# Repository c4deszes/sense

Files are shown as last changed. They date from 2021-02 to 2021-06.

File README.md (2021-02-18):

# Environment sensor



> This project implements an environment sensor, including PCB, enclosure and
software.

---

## Features

+ WiFi connection, configuration in AP mode
+ Publishes messages over MQTT
+ Measures several values, including:
  + Temperature
  + Humidity
  + Pressure
  + Dust concentration
  + Wind speed
  + Light level

## Help

### Documentation

The project uses AsciiDoctor as it's primary documentation format and Markdown
in a few places, such as this README.

[AsciiDoctor reference](https://docs.asciidoctor.org/asciidoc/latest/)

[AsciiDoctor Gradle plugin](https://asciidoctor.github.io/asciidoctor-gradle-plugin/development-3.x/user-guide)

### Traceability

Project is setup to have traceability from requirements to implementation and
verification but hasn't decided on a tool yet.

## License



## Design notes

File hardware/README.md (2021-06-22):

# Sensor Hardware

## Requirements

[List of hardware requirements](./docs/requirements)

## Design

[Hardware design overview](./docs/design/hardware.adoc)

## Development process

Development process according to [Hardware SPICE](https://www.intacs.info/images/uploads/intacs_HW_Engineering_PRM_PAM_v20.pdf).

---

## Development tools

| Tool | Version | Purpose |
|--|--|--|
| KiCAD | 5.1+ | Schematic design, PCB layout |
| Python | 3.8+ | *Optional*, used for scripted workflow |

---

## Continuous Integration

GitHub Actions is used for automatically testing some aspects of the design on
each change.

[KiBot](https://github.com/INTI-CMNB/kibot)

[KiCAD Export actions](https://github.com/nerdyscout/kicad-exports)

---

## Helpful links

[Hardware Software Interface](https://nqa2.iscn.com/images/PdfFiles/experience-aspice-safety-integrated.pdf)

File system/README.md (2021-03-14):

# Sensor System

## Requirements

[List of system requirements](./docs/requirements)

## Architecture

[System architecture overview](./docs/architecture/system.adoc)

---

## Continuous Integration

GitHub Actions is used for the system tests that can automatically executed.

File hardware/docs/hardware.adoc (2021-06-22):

= Hardware domain overview

== Hardware Requirements

- xref:requirements/power.adoc[Power requirements]
- xref:requirements/sensor.adoc[Sensor requirements]

== Hardware Design

- xref:design/hardware.adoc[Hardware design overview]
- xref:design/controller.adoc[Controller design]
- xref:design/power.adoc[Power design]
- xref:design/sensor.adoc[Sensor design]
- xref:design/windsensor.adoc[Wind Sensor design]

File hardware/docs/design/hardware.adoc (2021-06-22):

= Hardware design

== Design overview

[plantuml,software-architecture-details,svg]
....
@startuml
!include C4_Component.puml

LAYOUT_LEFT_RIGHT()

title Sensor Hardware

System_Boundary(hardware, "Hardware") {
	Component(power, "Power", "Power", "Provides power to all components")

	System_Boundary(sensor, "Sensor") {
		Component(bme280, "BME280", "Sensor")
		Component(bh1750, "BH1750", "Sensor")
		Component(gp2y1010au, "GP2Y1010AU", "Sensor")
	}

	Component(windsensor, "Wind Sensor", "Sensor", "")

	Component(controller, "Controller", "", "")

	Rel(power_connector, power, "Power")
}
....

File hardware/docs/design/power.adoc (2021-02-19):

= Power design

== DC/DC converter

link:https://www.st.com/resource/en/datasheet/l5973d.pdf[L5973D Datasheet]

link:https://www.st.com/resource/en/application_note/cd00043744-designing-with-the-25-a-dcdc-converter-l5973d-stmicroelectronics.pdf[L5973D Application note]

== Linear regulator

link:https://www.microchip.com/wwwproducts/en/MIC5234[MIC5234 Datasheet]

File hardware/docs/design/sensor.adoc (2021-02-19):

= Sensor design

== Temperature/Humidity/Pressure Sensor

link:https://www.bosch-sensortec.com/media/boschsensortec/downloads/datasheets/bst-bme280-ds002.pdf[BME280 Datasheet]

== Light Sensor

link:https://www.mouser.com/datasheet/2/348/bh1750fvi-e-186247.pdf[BH1750 Datasheet]

== Dust Sensor

link:https://global.sharp/products/device/lineup/data/pdf/datasheet/gp2y1010au_e.pdf[GP2Y1010AU Datasheet]

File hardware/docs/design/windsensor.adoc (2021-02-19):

= Wind Sensor design

== Constant Power supply

link:https://datasheets.maximintegrated.com/en/ds/MAX4210-MAX4211.pdf[MAX4210 Datasheet]

link:https://www.maximintegrated.com/en/design/technical-documents/app-notes/4/4470.html[MAX4210 Constant Power PSU Application note]

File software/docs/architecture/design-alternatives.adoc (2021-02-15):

= Software architecture Design alternatives

== No aggregate

The Sensor Aggregator may be seen as a monolith pattern, the alternative would
be to wire each sensor to the modules that depend on it.

|===
|*Pro* | *Con*

|Monolith is avoided, in case of a new sensor only the dependent modules have to
be modified
|Too many dependencies having to be injected into the other modules
|===

== Merging Application Main with Signal Publisher

The Signal Publisher doesn't have many responsibilities therefore it could
be merged into Application Main.

|===
|*Pro* | *Con*

|Reduces complexity of the architecture
|Increases complexity of Application Main
|===

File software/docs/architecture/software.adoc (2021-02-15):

= Software architecture overview

This document describes the overall software architecture and their interactions,
as well as integration of the software into larger systems.

== Architecture

Below is a diagram of the software architecture.

[plantuml,software-architecture-details,svg]
....
@startuml
!include C4_Component.puml

LAYOUT_LEFT_RIGHT()

title Sensor Software Architecture

System_Boundary(software, "Software") {
	System_Boundary(comm, "Communication Layer") {
		Component(wifi, "WiFi Connection Manager", "WiFi", "Provides access to the WiFi connection")
		Component(mqtt, "MQTT Connection Manager", "Mqtt", "Provides access to the MQTT connection")
		Component(serial, "Serial Connection Manager", "Serial", "Provides access to the Serial connection")

		Rel(mqtt, wifi, "GetNetworkInterface")
	}
	System_Boundary(sensor, "Sensor Layer") {
		Container(sensor_aggregator, "Sensor Aggregator", "Sensors", "Aggregates all sensor values and states into a single interface")
		Component(temperature, "Temperature Sensor", "Sensor", "Provides temperature values")
		Component(humidity, "Humidity Sensor", "Sensor", "Provides humidity values")
		Component(pressure, "Pressure Sensor", "Sensor", "Provides pressure values")
		Component(dust, "Dust Sensor", "Sensor", "Provides dust concentration values")
		Component(light, "Light Sensor", "Sensor", "Provides light level values")
		Component(wind, "Wind Sensor", "Sensor", "Provides wind speed values")

		Component(power, "Power Handler", "Sensor", "Provides power monitoring and low power control")

		Rel(sensor_aggregator, temperature, "GetValue")
		Rel(sensor_aggregator, humidity, "GetValue")
		Rel(sensor_aggregator, pressure, "GetValue")
		Rel(sensor_aggregator, dust, "GetValue")
		Rel(sensor_aggregator, light, "GetValue")
		Rel(sensor_aggregator, wind, "GetValue")
		Rel(sensor_aggregator, power, "GetValue")
		Rel(sensor_aggregator, power, "Enter Low Power Mode")
	}
	System_Boundary(app, "Application Layer") {
		Component(application, "Application Main", "Application", "Executes main application code")
		Component(configuration, "Configuration Manager", "Configuration", "Provides access to non-volatile memory")
		Component(diagnostics, "Diagnostics Controller", "Diagnostics", "Provides diagnostic access to the device")
		Component(publisher, "Signal Publisher", "Publisher", "Periodically sends out sensor values")

		Rel(application, publisher, "")
		Rel(application, diagnostics, "")
		Rel(application, configuration, "")
	}

	Rel(diagnostics, wifi, "GetNetworkInterface")
	Rel(diagnostics, serial, "GetSerialInterface")
	Rel(diagnostics, sensor_aggregator, "GetSensorValues")
	Rel(publisher, mqtt, "Publish Message")
	Rel(publisher, sensor_aggregator, "GetSensorValues")
	Rel(application, sensor_aggregator, "Enter Low Power Mode")
}

System_Ext(hardware, "Hardware") {
	Component_Ext(powerstage, "DC/DC", "Power")
	Component_Ext(bme280, "BME280", "Ambient sensor")
	Component_Ext(gp2y1010au, "GP2Y1010", "Dust sensor")
	Component_Ext(bh1750, "BH1750", "Light sensor")
	Component_Ext(anemometer, "Anemometer", "Wind sensor")
	Component_Ext(ublox, "U-Blox NINA", "WiFi")
	Component_Ext(uart, "UART Header", "")
	Component_Ext(nvram, "AT24C02", "NVRAM")
}

BiRel(power, powerstage, "Control/Monitor", "Analog/Digital")
BiRel(temperature, bme280, "Communication", "I2C")
BiRel(humidity, bme280, "Communication", "I2C")
BiRel(pressure, bme280, "Communication", "I2C")
BiRel(dust, gp2y1010au, "Control", "Analog")
BiRel(light, bh1750, "Communication", "I2C")
BiRel(wind, anemometer, "Control", "Analog")
BiRel(wifi, ublox, "Communication", "SPI")
BiRel(serial, uart, "Communication", "UART")
BiRel(configuration, nvram, "Communication", "I2C")

@enduml
....

=== Elements

==== Application Layer

- xref:elements/application/ApplicationMain.adoc[Application Main]
- xref:elements/application/ConfigurationManager.adoc[Configuration Manager]
- xref:elements/application/DiagnosticsController.adoc[Diagnostics Controller]
- xref:elements/application/SignalPublisher.adoc[Signal Publisher]

==== Communication Layer

- xref:elements/communication/MQTTConnectionManager.adoc[MQTT Connection Manager]
- xref:elements/communication/SerialConnectionManager.adoc[Serial Connection Manager]
- xref:elements/communication/WiFiConnectionManager.adoc[WiFi Connection Manager]

==== Sensor Layer

- xref:elements/sensor/DustSensor.adoc[Dust Sensor]
- xref:elements/sensor/HumiditySensor.adoc[Humidity Sensor]
- xref:elements/sensor/LightSensor.adoc[Light Sensor]
- xref:elements/sensor/PowerHandler.adoc[Power Handler]
- xref:elements/sensor/PressureSensor.adoc[Pressure Sensor]
- xref:elements/sensor/TemperatureSensor.adoc[Temperature Sensor]
- xref:elements/sensor/WindSensor.adoc[Wind Sensor]

== Software integration

=== Standard mode (MQTT)

When WiFi and MQTT settings are correctly configured then the sensors can publish
data through the MQTT broker and applications can subscribe to the messages.

[blockdiag,mqtt-integration,svg]
....
blockdiag {
  app [label = "Application"];
  broker [label = "MQTT Broker"];
  sensor1 [label = "Sensor 1"];
  sensor2 [label = "Sensor 2"];
  sensor3 [label = "Sensor 3"];

  app <- broker;
  broker <- sensor1;
  broker <- sensor2;
  broker <- sensor3;
}
....

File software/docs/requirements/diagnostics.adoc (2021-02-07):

= Diagnostics

This document specifies the diagnostic software requirements of the product.

== Requirements

=== Interfaces

The diagnostic mode shall be accessible via UART, the baudrate shall be 115200bps
with 8 data bit, even parity and a single stop bit (115200/8/E/1).

The diagnostic mode shall also be available in WiFi access point mode, and in
WiFi station mode if it's enabled.

=== Product information

In diagnostic mode the following commands shall be available:

- Read Serial Number
- Read MAC Address

=== Product state

In diagnostic mode the following commands shall be available:

- Read Power sensor
- Read Temperature sensor
- Read Humidity sensor
- Read Pressure sensor
- Read Dust sensor
- Read Wind speed sensor
- Read Light level sensor

- Reload configuration
- Reset

=== Connection state

In diagnostic mode the following commands shall be available:

- Read WiFi status
- Read Last WiFi station connection status
- Read MQTT connection status

- Reconnect

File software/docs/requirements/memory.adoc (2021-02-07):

= Memory and configuration

== Requirements

=== Product information

The software shall store information about the product instance.

The following product information shall be stored in non volatile memory.

- Product Serial number
- Software version number

=== WiFi configuration

The software shall store the WiFi configuration in non volatile memory.

The following WiFi settings shall be stored in non volatile memory.

- WiFi SSID
- WiFi Password

=== MQTT configuration

The software shall store the MQTT configuration in non volatile memory.

The following MQTT settings shall be stored in non volatile memory.

- MQTT broker hostname
- MQTT broker port
- MQTT username
- MQTT password
- MQTT topic name

=== Diagnostic settings

The software shall store the configuration of Diagnostics in non volatile memory.

The following diagnostic settings shall be stored in non volatile memory.

- Diagnostics over WiFi AP enabled
- Diagnostics over WiFi STA enabled

=== Dust sensor calibration information

The software shall store dust sensor calibration information in non volatile memory.

=== Anemometer calibration information

The software shall store wind sensor calibration information in non volatile memory.

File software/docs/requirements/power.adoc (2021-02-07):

= Power requirements

This document specifies the software requirements for managing product power.

== Requirements

=== Voltage monitoring

The product shall monitor it's input voltage and keep a 

=== Current consumption

The product shall not consume more than _maximum current_ under any operating conditions.

The produt shall not consume more than _sleep mode current_ in sleep mode.

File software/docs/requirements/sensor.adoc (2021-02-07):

= Sensor requirements

== Sensor stack

The following values are measured:

- Ambient temperature
- Relative humidity
- Air pressure
- Dust concentration
- Wind speed
- Light level

=== Capabilities

The product shall be able to measure environment states according to table below.

== Sensor states

On power on reset each sensor shall start in *NO_INIT* state.

The microcontroller shall attempt to initialize each sensor individually then
based on the internal communication, peripheral states shall decide whether
the sensor is functional and assign either *INIT_OK* or *INIT_ERROR* states
accordingly.

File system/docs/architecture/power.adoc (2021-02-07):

= Power component design

== Interface

The power interface provides physical power to hardware components, the input
voltage value and the input voltage state.

== Parameters

[format="csv", options="header"]
|===
include::system/params/power.csv[]
|===

== Power monitoring

=== States

The power component inherits the xref:sensor.adoc#States[sensor statemachine] and extends it with it's
own statemachine with the purpose of providing other components information of possibly damaging
or edge case conditions. Components may reference the states below and use them for error reactions.

[nomnoml]
....
#direction: right
#spacing: 60
[<start>s]->[<state>NA]
[<state>NA]->[<state>OK]
[<state>NA]overvoltage->[<state>HIGH]
[<state>NA]undervoltage->[<state>LOW]
[<state>OK]overvoltage->[<state>HIGH]
[<state>OK]undervoltage->[<state>LOW]
[<state>LOW]overvoltage->[<state>HIGH]
[<state>LOW]->[<state>OK]
[<state>HIGH]undervoltage->[<state>LOW]
[<state>HIGH]->[<state>OK]
....

==== Description

The component starts in an _NA_ state and switches between LOW, OK, HIGH states
after every sample depending on the sensed voltage value.

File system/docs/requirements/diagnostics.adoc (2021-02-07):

= Diagnostic requirements

This document specifies the diagnostic requirements of the product.

== Parameters

[format="csv", options="header"]
|===
include::system/params/communication.csv[]
|===

[format="csv", options="header"]
|===
include::system/params/diagnostics.csv[]
|===

== Requirements

=== Interfaces

The diagnostic mode shall be be accessible via UART headers on the PCB or via
a TCP server hosted when the product is in WiFi access point mode.

=== Product information

In diagnostic mode the following product information shall be readable:

- Product Serial number
- Product MAC address

=== Product state

In diagnostic mode the following status information shall be readable:

- Power state
- Temperature sensor state
- Humidity sensor state
- Pressure sensor state
- Dust sensor state
- Wind speed sensor state
- Light level sensor state

=== Connection state

In diagnostic mode the following connection status information shall be readable:

- Current WiFi connection mode
- Current WiFi connection status
- Last WiFi station connection status
- Current MQTT connection status

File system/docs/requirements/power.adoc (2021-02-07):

= Power requirements

This document specifies the requirements of the power input.

== Parameters

[format="csv", options="header"]
|===
include::system/params/power.csv[]
|===

== Requirements

=== Operational voltage

The product shall be operational when the supply voltage is above
<<Parameters,param_power_low_error>> and below
<<Parameters,param_power_high_error>>

=== Reverse voltage

The product shall be operational when the supply voltage is restored after
a reverse or negative supply voltage event.

=== Voltage monitoring

The product shall monitor it's input voltage.

=== Current consumption

The product shall not consume more than <<Parameters,param_power_max_current>>
under any operating conditions.

The produt shall not consume more than
<<Parameters,param_power_max_sleep_current>> in sleep mode.

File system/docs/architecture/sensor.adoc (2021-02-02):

= Sensor components

== Common sensor component

=== Interface

Each sensor provides the following values:

- Sensor state _(INIT_OK, INIT_ERROR)_
- Sensor value state _(OK, LOW, HIGH, etc.)_
- Sensor value (floating point)

=== States

Each sensor implements the following state machine:

[nomnoml]
....
[<start>st]->[<state>NO_INIT]
[<state>NO_INIT]->[<choice>Has Error?]
[<choice>Has Error?] no ->[<state>INIT_OK]
[<choice>Has Error?] yes -> [<state>INIT_ERROR]
....

== Temperature sensor

=== States

The temperature sensor implements a statemachine that can indicate
overtemperature and freeze conditions.

[nomnoml]
....
[<start>st]->[<state>NA]
[<state>NA]->[<state>OK]
[<state>NA]->[<state>LOW]
[<state>NA]->[<state>HIGH]
[<state>OK]->[<state>LOW]
[<state>LOW]->[<state>OK]
[<state>OK]->[<state>HIGH]
[<state>HIGH]->[<state>OK]
....

== Humidty sensor

=== States

The humidty sensor implements a statemachine that can indicate too high
humidity for certain components to operate in.

[nomnoml]
....
[<start>st]->[<state>NA]
[<state>NA]->[<state>OK]
[<state>NA]->[<state>HIGH]
[<state>OK]->[<state>HIGH]
[<state>HIGH]->[<state>OK]
....

== Air pressure sensor

=== States

The air pressure sensor implements a statemachine that goes into _OK_ state
after the first successful value acquisition. No error reaction is tied to it's
value in the current design.

[nomnoml]
....
[<start>st]->[<state>NA]
[<state>NA]->[<state>OK]
[<state>OK]
....

== Dust concentration sensor

=== States

The dust concentration sensor implements a statemachine that goes into _OK_ state
after the first successful value acquisition. No error reaction is tied to it's
value in the current design.

[nomnoml]
....
[<start>st]->[<state>NA]
[<state>NA]->[<state>OK]
[<state>OK]
....

== Wind speed sensor

=== States

The wind speed sensor (anemometer) implements a statemachine that goes into _OK_ state
after the first successful value acquisition. Furthermore the anemometer may be be
disabled for hardware protection as well as go into a _SATURATED_ state where
the sensor value may start to max out.

[nomnoml]
....
[<start>st]->[<state>NA]
[<state>NA]->[<state>OK]
[<state>OK]->[<state>DISABLED]
[<state>DISABLED]->[<state>OK]
[<state>OK]->[<state>SATURATED]
[<state>SATURATED]->[<state>OK]
[<state>SATURATED]->[<state>DISABLED]
....

== Light level sensor

=== States

The light level sensor implements a statemachine that goes into _OK_ state
after the first successful value acquisition. No error reaction is tied to it's
value in the current design.

[nomnoml]
....
[<start>st]->[<state>NA]
[<state>NA]->[<state>OK]
[<state>OK]
....

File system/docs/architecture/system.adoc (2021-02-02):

= System architecture

This document describes the overall system architecture, along with examples of
how this product is integrated into larger systems.

== Architecture

The following diagram describes the product's internal architecture

[blockdiag]
....
blockdiag {
	power_in [label = "Power In"];
	power [label = "DC/DC converter"];
	communication [label = "u-blox NINA-W102"];
	processor [label = "ATSAMD21G18A"];
	boschsensor [label = "BME280"];
	dustsensor [label = "GP2Y1010AU"];
	lightsensor [label = "BH1750"];
	anemometer [label = "Anemometer"];

	power_in -> power;
	power -> processor;
	communication <-> processor;
	processor <- boschsensor;
	processor <- dustsensor;
	processor <- lightsensor;
	processor <-> anemometer;
}
....

=== Detailed designs

- xref:power.adoc[Power component]
- xref:sensor.adoc[Sensor]
- xref:communication.adoc[Communication]

== Product integration

The product is intended to be integrated into a larger system consisting of
multiple sensors and potentially actuators.

The product can be part of a network where multiple sensors publish messages
to the same message broker.

[nwdiag]
....
nwdiag {
  network WiFi {
    "MQTT broker" [address = "mqtt.broker.local"];
    Sensor1 [address = "192.168.1.2"];
    Sensor2 [address = "192.168.1.3"];
	Sensor3 [address = "192.168.1.4"];
  }
}
....

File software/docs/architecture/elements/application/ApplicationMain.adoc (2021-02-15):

= Application Main

The application main handles the software initialization after reset, the cyclic update of components and the main state transitions such as low power mode.

== Requirements

== Interfaces

=== Setup

[cols="h,1"]
|===
|Function |setup
|Returns |-
|Description |Initializes all the other software components
|===

=== Loop

[cols="h,1"]
|===
|Function |loop
|Returns |-
|Description |Periodically updates all the software components
|===

== Dynamic behavior

[nomnoml]
....
[<start>st] power on reset -> [<state>setup]
[<state>setup] initialized -> [<state>loop]
[<state>loop] -> [<state>loop]
....

== Resource consumption

=== Memory

[cols="h,1"]
|===
|RAM |5%
|ROM |5%
|===

=== Runtime

|===
|Function |Average |Max
|setup |100ms |500ms
|loop |100ms |500ms
|===

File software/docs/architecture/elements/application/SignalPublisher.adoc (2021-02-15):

= Application Main

== Requirements

== Interfaces

=== Publish

[cols="h,1"]
|===
|Function |publish
|Returns |-
|Description |Publishes the current sensor values over MQTT
|===

== Dynamic behavior

// TODO: describe dynamic behavior

== Resource consumption

=== Memory

[cols="h,1"]
|===
|RAM |<1%
|ROM |1%
|===

=== Runtime

|===
|Function |Average |Max
|publish |10ms |100ms
|===

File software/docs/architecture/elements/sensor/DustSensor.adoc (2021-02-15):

= Dust Sensor

== Requirements

== Interfaces

=== Initialize

[cols="h,1"]
|===
|Function |begin
|Returns |-
|Description |Initializes the sensor hardware
|===

=== GetState

[cols="h,1"]
|===
|Function |getState
|Returns |Sensor state `INIT_OK` or `INIT_ERROR`
|Description |Returns sensor hardware state
|===

=== GetValue

[cols="h,1"]
|===
|Function |getValue
|Returns |Sensor value `float`
|Description |Returns currently measured sensor value
|===

=== GetValueState

[cols="h,1"]
|===
|Function |getValueState
|Returns |Sensor value
|Description |Returns sensor value state
|===

== Dynamic behavior

//TODO: describe dynamic behavior

== Resource consumption

=== Memory

[cols="h,1"]
|===
|RAM |<1%
|ROM |1%
|===

=== Runtime

|===
|Function |Average |Max
|begin |50ms |100ms
|getValue |10ms |20ms
|===

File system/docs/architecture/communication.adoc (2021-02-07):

= Communication component

== Interface

The communication component provides the following interfaces:

- WiFi connection
- MQTT connection
- Diagnostic input and output

== Parameters

[format="csv", options="header"]
|===
include::system/params/communication.csv[]
|===

== States

=== WiFi

The following diagram describes the WiFi connection's statemachine.

[nomnoml]
....
[<start>st]->[<state>NO_INIT]
[<state>NO_INIT]->[<choice>Has module error?]
[Has module error?] no ->[<state>AP_MODE]
[Has module error?] yes -> [<state>INIT_ERROR]
[AP_MODE] on timer elapsed & wifi ssid configured & no client connected -> [<state>STA_DISCONNECTED]
[STA_DISCONNECTED] on first attempt / retry timeout -> [<state>STA_CONNECTING]
[STA_CONNECTING] on success -> [<state>STA_CONNECTED]
[STA_CONNECTING] on timeout -> [STA_DISCONNECTED]
[STA_CONNECTED] on dropout -> [STA_DISCONNECTED]
....

==== Description

The component starts in uninitialized state and goes into Access Point mode if
the module initialization has succeeded. The component stays in this state until
either a client is connected, the internal timer has not elapsed or WiFi settings
are not configured. Once all of this conditions are gone the component will attempt
to connect to the configured Access Point.

=== MQTT

The following diagram describes the MQTT connection's statemachine.

[nomnoml]
....
[<start>st]->[<state>NO_INIT]
[<state>NO_INIT] on WiFi entering STA_CONNECTED -> [<state>MQTT_DISCONNECTED]
[MQTT_DISCONNECTED] on first attempt / retry timeout -> [<state>MQTT_CONNECTING]
[<state>MQTT_CONNECTING] on success -> [<state>MQTT_CONNECTED]
[MQTT_CONNECTING] on timeout -> [MQTT_DISCONNECTED]
[MQTT_CONNECTED] on dropout -> [MQTT_DISCONNECTED]
....

==== Description

The component starts in uninitialized state and goes into disconnected state once
WiFi has successfully connected to an Access Point. The component then will try
and periodically attempt to connect to the configured broker.

Once the device has successfully connected it will start broadcasting the sensor
values.

=== Diagnostics

The following diagram describes the Diagnostic TCP server's statemachine.

[nomnoml]
....
[<start>st]->[<state>NO_INIT]
[<state>NO_INIT] on WiFi AP Mode -> [<state>DIAGNOSTIC_TCP_DISCONNECTED]
[<state>DIAGNOSTIC_TCP_DISCONNECTED] on connect -> [<state>DIAGNOSTIC_TCP_CONNECTED]
[<state>DIAGNOSTIC_TCP_DISCONNECTED] on timeout -> [<end>end]
[<state>DIAGNOSTIC_TCP_CONNECTED] on disconnect -> [<state>DIAGNOSTIC_TCP_DISCONNECTED]
[<state>DIAGNOSTIC_TCP_CONNECTED] on connection forced -> [<end>end]
....

==== Description

The component starts in uninitialized state and goes into disconnected state once
the WiFi has entered Access Point mode. The component will wait for a TCP connection
on the diagnostic TCP port, while this connection

== Sequences

=== First boot

Device is not yet configured, configuration is provided by the user via
diagnostic TCP server.

[seqdiag]
....
seqdiag {
  Communication -> WiFi [label = "InitModule"];
  Communication <-- WiFi [label = "INIT_OK"];

  Communication -> WiFi [label = "StartAp"];
  Communication <-- WiFi [label = "AP_MODE"];

  === User configures WiFi & MQTT settings ===

  Communication -> Diagnostics [label = "ConnectClient"];
  Communication <-- Diagnostics [label = ""];

  Diagnostics -> WiFi [label = "Set Configuration"];
  Diagnostics <-- WiFi [label = "OK"];

  Diagnostics -> MQTT [label = "Set Configuration"];
  Diagnostics <-- MQTT [label = "OK"];

  Diagnostics -> Communication [label = "Reload"];
  Diagnostics <-- Communication [label = ""];

  === Communication Startup ===

  Communication -> WiFi [label = "StartSta"];
  Communication <-- WiFi [label = "STA_CONNECTED"];

  Communication -> MQTT [label = "ConnectMqtt"];
  Communication <-- MQTT [label = "MQTT_CONNECTED"];
}
....

=== Successful connection

Device is already configured with the correct WiFi and MQTT settings and the
connections succeed.

[seqdiag]
....
seqdiag {
  Communication -> WiFi [label = "InitModule"];
  Communication <-- WiFi [label = "INIT_OK"];

  Communication -> WiFi [label = "StartAp"];
  Communication <-- WiFi [label = "AP_MODE"];

  ... AP Mode timeout, no active connection ...

  Communication -> WiFi [label = "StartSta"];
  Communication <-- WiFi [label = "STA_CONNECTED"];

  Communication -> MQTT [label = "ConnectMqtt"];
  Communication <-- MQTT [label = "MQTT_CONNECTED"];
}
....

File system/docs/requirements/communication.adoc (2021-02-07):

= Communication requirements

This document specifies the communication requirements of the product.

== Parameters

[format="csv", options="header"]
|===
include::system/params/communication.csv[]
|===

== Requirements

=== WiFi Communication

The product shall act as a WiFi station.

=== WiFi Configuration

The WiFi configuration shall be configurable via the
xref:diagnostics.adoc[diagnostic mode].

=== WiFi States

On power on reset the product shall detect if there's a problem initializing
the WiFi module and set it's internal state accordingly.

On power on reset the product shall act a WiFi Access Point for atleast
<<Parameters,param_wifi_ap_por_timeout>> or more if there's an active client
connection, afterwards the product shall attempt to connect to the configured 
WiFi Access Point as a Station. 
If the WiFi isn't configured correctly (empty SSID) the product shall stay in
AP mode until configuration is set and the device is either reset or connection
is forced via diagnostic commands.

If the product is unable to connect within
<<Parameters,param_wifi_sta_connection_timeout>> then the product shall attempt
reconnecting after <<Parameters,param_wifi_sta_retry_timeout>>.

=== MQTT Communication

The product shall publish MQTT messages.

=== MQTT Configuration

The MQTT configuration shall be configurable via the
xref:diagnostics.adoc[diagnostic mode].

=== MQTT States

After the product has successfully connected to the configured WiFi Access Point
it shall attempt to connect to the configured MQTT broker, unless there's configuration
missing.

If the product is unable to connect within
<<Parameters,param_mqtt_connection_timeout>> then the product shall attempt
reconnecting after <<Parameters,param_mqtt_retry_tmeout>>.

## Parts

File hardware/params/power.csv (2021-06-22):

Id | Parameter | Value | Unit
param_power_input_min | Maximum Input Voltage | 6.0 | V
param_power_input_max | Maximum Input Voltage | 32.0 | V
param_power_reverse_leakage | Maximum Input Voltage | 100 | uA

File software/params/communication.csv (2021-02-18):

Id | Parameter | Value | Unit
param_mqtt_publish_interval | MQTT publish interval | 5000 | ms

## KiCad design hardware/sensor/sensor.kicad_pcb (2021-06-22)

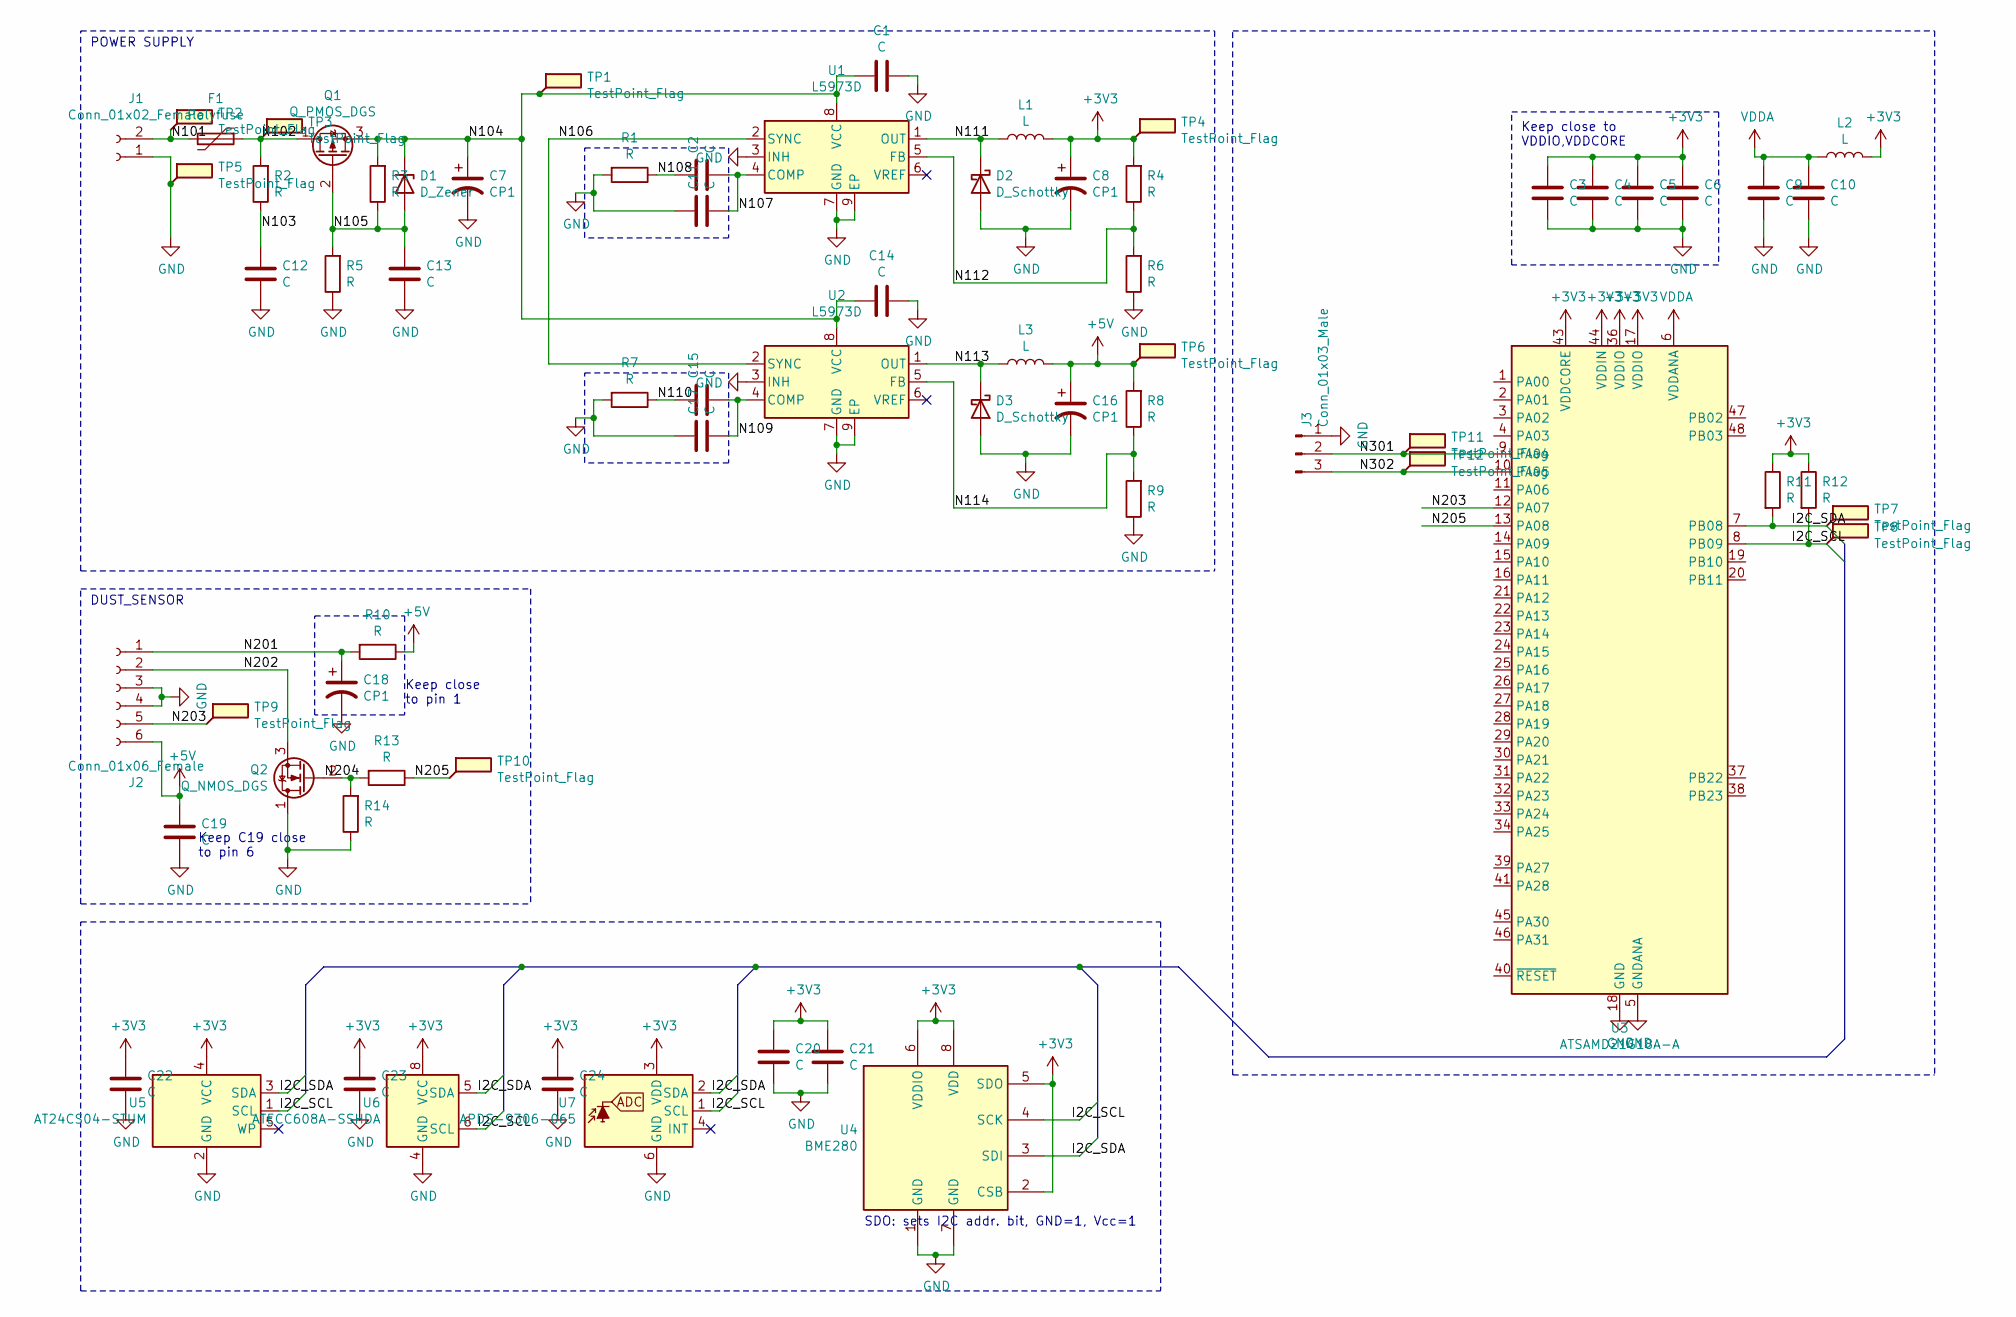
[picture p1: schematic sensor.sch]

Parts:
C1, C2, C3, C4, C5, C6, C9, C10, C11, C12, C13, C14, C15, C17, C19, C20, C21, C22, C23, C24: C; C_0603_1608Metric
C7, C8, C16, C18: CP1; CP_Elec_6.3x7.7
D1: D_Zener; D_SOD-110
D2, D3: D_Schottky; D_SMB_Handsoldering
F1: Polyfuse; Fuse_1812_4532Metric
J1: Conn_01x02_Female; JST_EH_S2B-EH_1x02_P2.50mm_Horizontal
J2: Conn_01x06_Female; PinHeader_1x06_P2.54mm_Vertical
J3: Conn_01x03_Male; PinHeader_1x03_P2.54mm_Vertical
L1, L3: L; L_Bourns-SRN4018
L2: L; L_0805_2012Metric
Q1: Q_PMOS_DGS; TO-252-2
Q2: Q_NMOS_DGS; SOT-23
R1, R2, R3, R4, R5, R6, R7, R8, R9, R10, R11, R12, R13, R14: R; R_0603_1608Metric
TP1, TP2, TP3, TP4, TP5, TP6, TP7, TP8, TP9, TP10, TP11, TP12: TestPoint_Flag; TestPoint_Pad_D1.5mm
U1, U2: L5973D; HSOP-8-1EP_3.9x4.9mm_P1.27mm_EP2.41x3.1mm_ThermalVias
U3: ATSAMD21G18A-A; TQFP-48_7x7mm_P0.5mm
U4: BME280; Bosch_LGA-8_2.5x2.5mm_P0.65mm_ClockwisePinNumbering
U5: AT24CS04-STUM; SOT-23-5
U6: ATECC608A-SSHDA; SOIC-8_3.9x4.9mm_P1.27mm
U7: APDS-9306-065; Broadcom_DFN-6_2x2mm_P0.65mm

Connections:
+3V3: C3.1, C4.1, C5.1, C6.1, C8.1, C20.1, C21.1, C22.1, C23.1, C24.1, L1.2, L2.2, R4.2, R11.1, R12.1, TP4.1, U3.17 (VDDIO), U3.36 (VDDIO), U3.43 (VDDCORE), U3.44 (VDDIN), U4.2 (CSB), U4.5 (SDO), U4.6 (VDDIO), U4.8 (VDD), U5.4 (VCC), U6.8 (VCC), U7.3 (VDD)
+5V: C16.1, C19.1, J2.6, L3.2, R8.2, R10.1, TP6.1
/I2C_SCL: R12.2, TP8.1, U3.8 (PB09), U4.4 (SCK), U5.1 (SCL), U6.6 (SCL), U7.1 (SCL)
/I2C_SDA: R11.2, TP7.1, U3.7 (PB08), U4.3 (SDI), U5.3 (SDA), U6.5 (SDA), U7.2 (SDA)
/N101: F1.2, J1.2, TP2.1
/N102: F1.1, Q1.1 (D), R2.2, TP3.1
/N103: C12.1, R2.1
/N104: C1.1, C7.1, C14.1, D1.1 (K), Q1.3 (S), R3.2, TP1.1, U1.8 (VCC), U2.8 (VCC)
/N105: C13.1, D1.2 (A), Q1.2 (G), R3.1, R5.2
/N106: U1.2 (SYNC), U2.2 (SYNC)
/N107: C2.2, C11.2, U1.4 (COMP)
/N108: C2.1, R1.1
/N109: C15.2, C17.2, U2.4 (COMP)
/N110: C15.1, R7.1
/N111: D2.1 (K), L1.1, U1.1 (OUT)
/N112: R4.1, R6.2, U1.5 (FB)
/N113: D3.1 (K), L3.1, U2.1 (OUT)
/N114: R8.1, R9.2, U2.5 (FB)
/N201: C18.1, J2.1, R10.2
/N202: J2.2, Q2.3 (S)
/N203: J2.5, TP9.1, U3.12 (PA07)
/N205: R13.1, TP10.1, U3.13 (PA08)
/N301: J3.2, TP11.1, U3.9 (PA04)
/N302: J3.3, TP12.1, U3.10 (PA05)
GND: C1.2, C3.2, C4.2, C5.2, C6.2, C7.2, C8.2, C9.2, C10.2, C11.1, C12.2, C13.2, C14.2, C16.2, C17.1, C18.2, C19.2, C20.2, C21.2, C22.2, C23.2, C24.2, D2.2 (A), D3.2 (A), J1.1, J2.3, J2.4, J3.1, Q2.1 (D), R1.2, R5.1, R6.1, R7.2, R9.1, R14.1, TP5.1, U1.3 (INH), U1.7 (GND), U1.9 (EP), U2.3 (INH), U2.7 (GND), U2.9 (EP), U3.5 (GNDANA), U3.18 (GND), U3.35 (GND), U3.42 (GND), U4.1 (GND), U4.7 (GND), U5.2 (GND), U6.4 (GND), U7.6 (GND)
unnamed: Q2.2 (G), R13.2, R14.2
VDDA: C9.1, C10.1, L2.1, U3.6 (VDDANA)

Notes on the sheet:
SDO: sets I2C addr. bit, GND=1, Vcc=1
DUST_SENSOR
POWER SUPPLY
Keep close to pin 1
Keep C19 close to pin 6
Keep close to VDDIO,VDDCORE

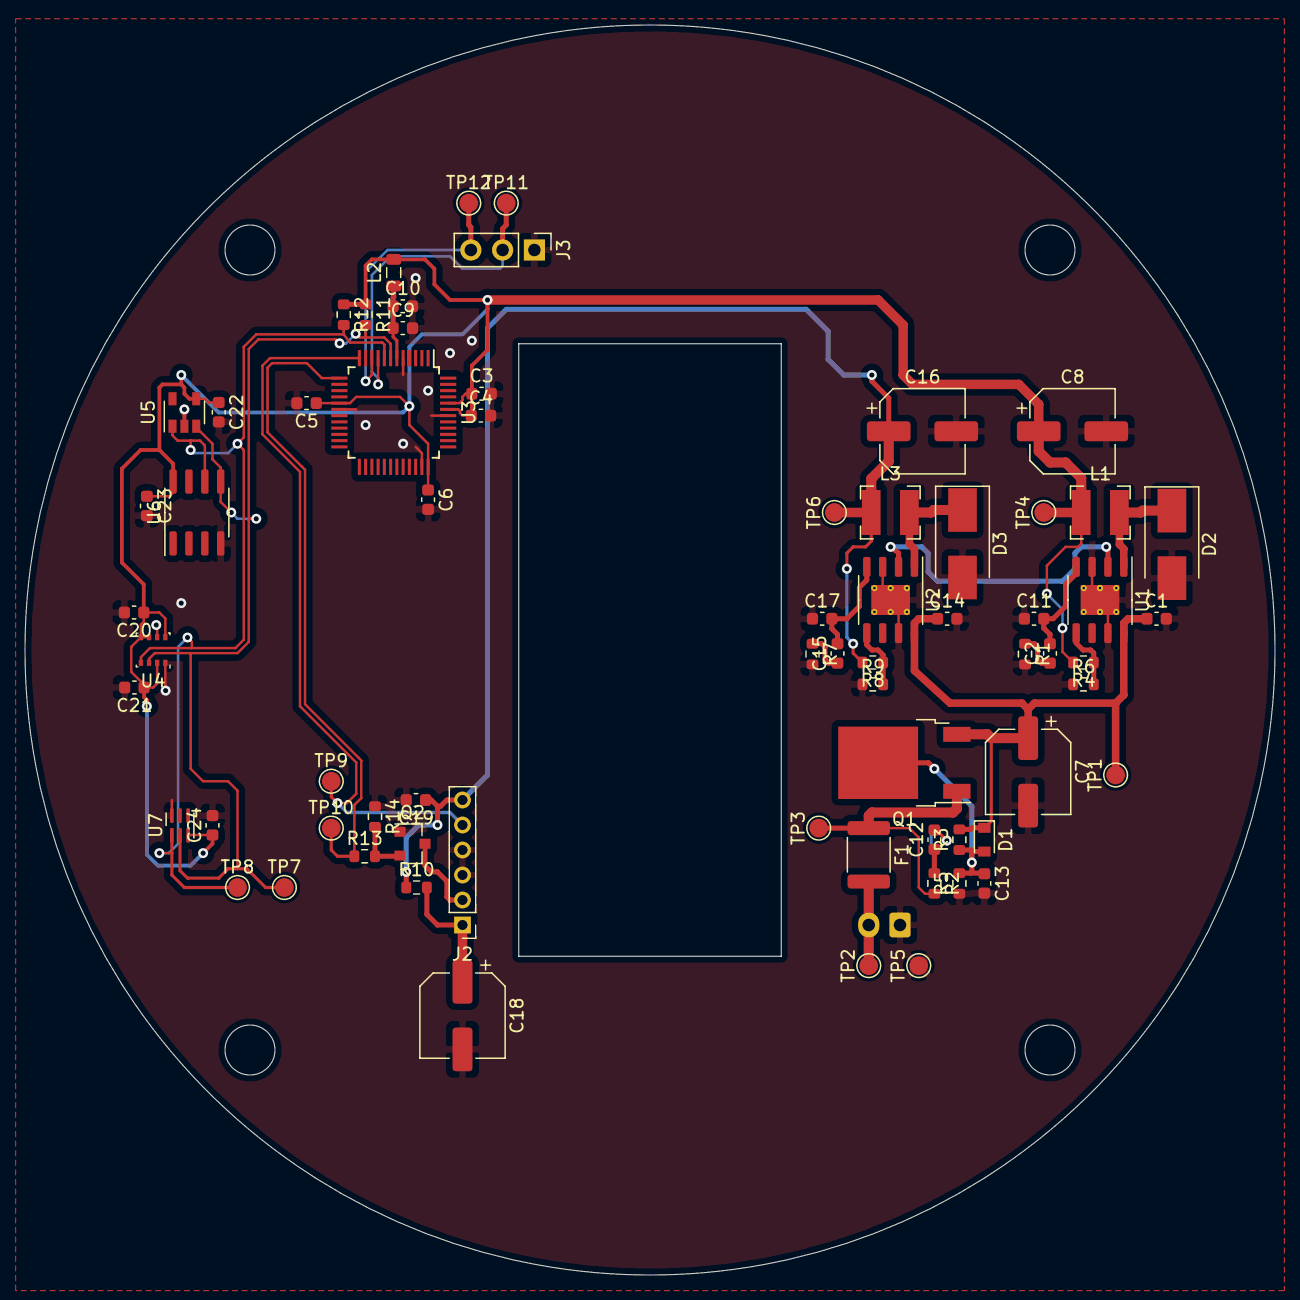
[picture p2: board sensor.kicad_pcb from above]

Board: 2 copper layers, 100.0 x 100.0 mm, 69 parts (1 on the bottom side), 27 nets.

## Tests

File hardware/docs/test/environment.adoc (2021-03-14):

= Test Environment

== Scope

- Power stage validation
- Anemometer driver circuit validation
- Temperature measurements
- Signal integrity check (I2C, UART signals)

== Instrumentation

=== Power supply

A programmable power supply is used to carry out measurements at different
input voltages.

=== Oscilloscope

An oscilloscope is used to check signal integrity.

=== DAQ

A Data acqusition unit is used to measure internal temperatures and validate
the internal signals of the anemometer circuit.

== Test framework

__TBD__

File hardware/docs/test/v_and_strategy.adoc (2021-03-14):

= Verification and Validation Strategy

== Process flow

[nomnoml]
....
[<start>st] -> [<choice>Design ready?]
[<choice>Design ready?]yes ->[<state>Perform electrical tests]
[<state>Perform electrical tests] success/failure -> [<end>release]
....

== Test Methods

=== Static testing

The hardware schematic and layout are tested within the toolchain for common
eletrical __(ERC)__ and design errors __(DRC)__.

== Test allocation

Static tests are automatically reexecuted on hardware design changes. The rest
may be partially automated or manual, depending on the complexity.

== Exit criteria

All tests must be executed before a hardware sample release and the release
report shall contain the measurements.

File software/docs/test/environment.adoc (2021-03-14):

= Test Environment

== Unit test environment

=== Scope

- Software component validation
- Application state transitions testing

== Hardware in loop environment

=== Scope

- Serial Diagnostic communication functional tests
- WiFi Diagnostic communication functional tests
- MQTT communication functional tests
- Memory configuration validation
- Voltage monitoring functional tests

=== Instrumentation

==== Power supply

A programmable power supply is used to test voltage monitoring feature.

==== Debugger

==== Serial device

A standard USB to Serial converter is used to communicate with the DUT over
the diagnostic channel.

=== Test framework

Pytest is used.

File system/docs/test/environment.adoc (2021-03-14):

= Test Environment

== Scope

- Power compliance tests
- Operational temperature functional tests
- Anemometer accuracy measurement

== Out of scope

- WiFi communication, MQTT communication (tested in Software)
- Light, Dust incident measurement (measurements taken over from part manufacturer)

== Instrumentation

=== Power supply

A programmable power supply is used to test power compliance.

=== Serial device

A standard USB to Serial converter is used to communicate with the DUT over
the diagnostic channel.

=== TBD

Climate chamber, wind tunnel.

== Test Framework

JavaTMC is used for interaction with measurement instrumentation with
JUnit5 as the surrounding Test framework.

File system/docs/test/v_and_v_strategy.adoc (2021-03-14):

= Verification and Validation Strategy

== Process flow

[nomnoml]
....
[<start>st] -> [<choice>Release ready?]
[<choice>Release ready?]yes ->[<state>Perform system tests]
[<state>Perform system tests] success/failure -> [<state>Perform safety/legal/security tests]
[<state>Perform safety/legal/security tests] failure -> [<choice>Release ready?]
[<state>Perform safety/legal/security tests] success -> [<end>release]
....

== Test Methods

=== Whitebox testing

Some internal signals can be observed through the diagnostic interface.
These will be used for measurements, because it's faster than doing data logging
over WiFi.

=== Blackbox testing

The product is tested through the interfaces that are also accessible to users.

== Test allocation

Some of the tests are automatically reexecuted on software, hardware, mechanics
changes and releases. The rest will be scheduled before a product release.

== Exit criteria

All tests must be executed before a product release and the release report
shall contain the number of passing, failing and skipped tests.

Safety, security and legal tests must pass before a product release.

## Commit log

2021-01-30 Initial commit
    Adds system requirements
    Adds system parameters
    Adds README and LICENSE
    [communication.csv, diagnostics.csv, power.csv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]
2021-02-02 Adds initial system architecture (#1)
    New WiFi requirements: module error and configuration error
    Adds System overview document
    Fixed links in system documentation
    Adds Gradle buildscripts for Asciidoc rendering
    [communication.csv, diagnostics.csv, power.csv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]
2021-02-07 Adds initial software requirements (#2)
    * Adds initial software requirements
    Adds asciidoc generator task to software project
    Doc builds run from root directory
    Fixes links in sw. comm. requirements
    Updates links in sys. requirements
    [communication.csv]
2021-02-18 Adds initial hardware requirements (#4)
    Adds hardware subproject
    Adds hardware parameters
    Adds hardware domain to PR labeler
    Fixes newline at the end of csv files causing errors in previews
    [communication.csv, diagnostics.csv, power.csv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]
2021-06-22 Initial hardware schematic and layout (#7)
    Adds KiCad schematic and layout
    Adds hardware parameters and HSI configuration
    Adds hardware workflow with Gerber, BOM, Layout and schematic export
    [power.csv, sensor.kicad_pcb, sensor.sch]

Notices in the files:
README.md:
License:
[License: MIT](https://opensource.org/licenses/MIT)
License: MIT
